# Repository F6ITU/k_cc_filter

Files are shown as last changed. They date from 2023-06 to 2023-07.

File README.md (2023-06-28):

# k_cc_filter
Simple DC filter for Power Switching Unit (12 or 45V) (codename "Boufiltre")

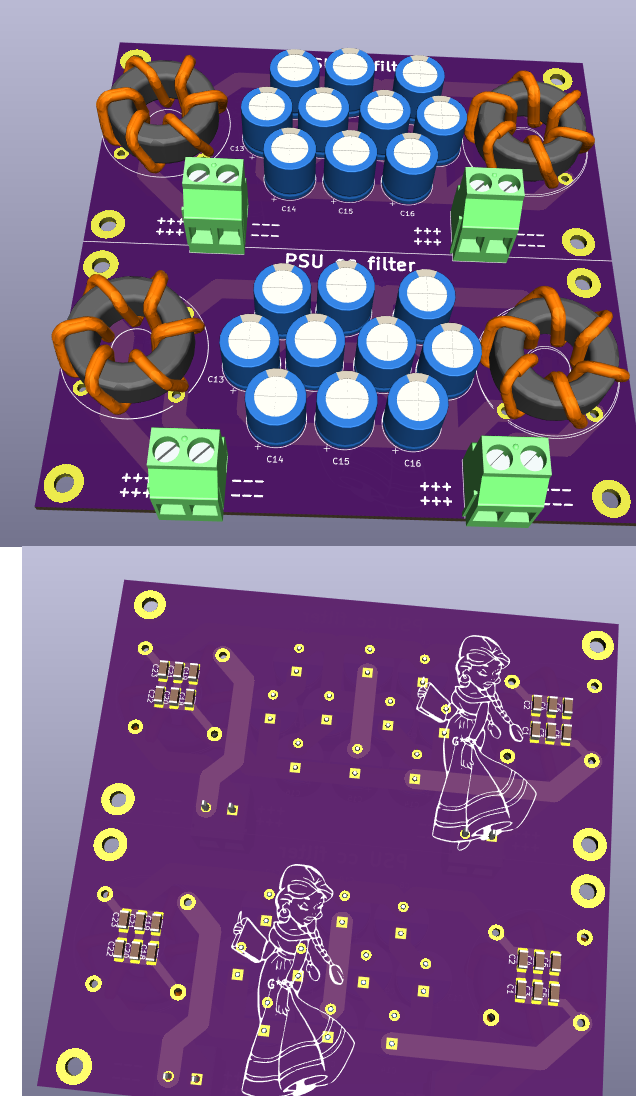
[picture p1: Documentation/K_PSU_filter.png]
Boufiltre cc filter for switching power supply


The whole network as a 100V service voltage 

L1/L4 could be omited and replaced by jumpers.

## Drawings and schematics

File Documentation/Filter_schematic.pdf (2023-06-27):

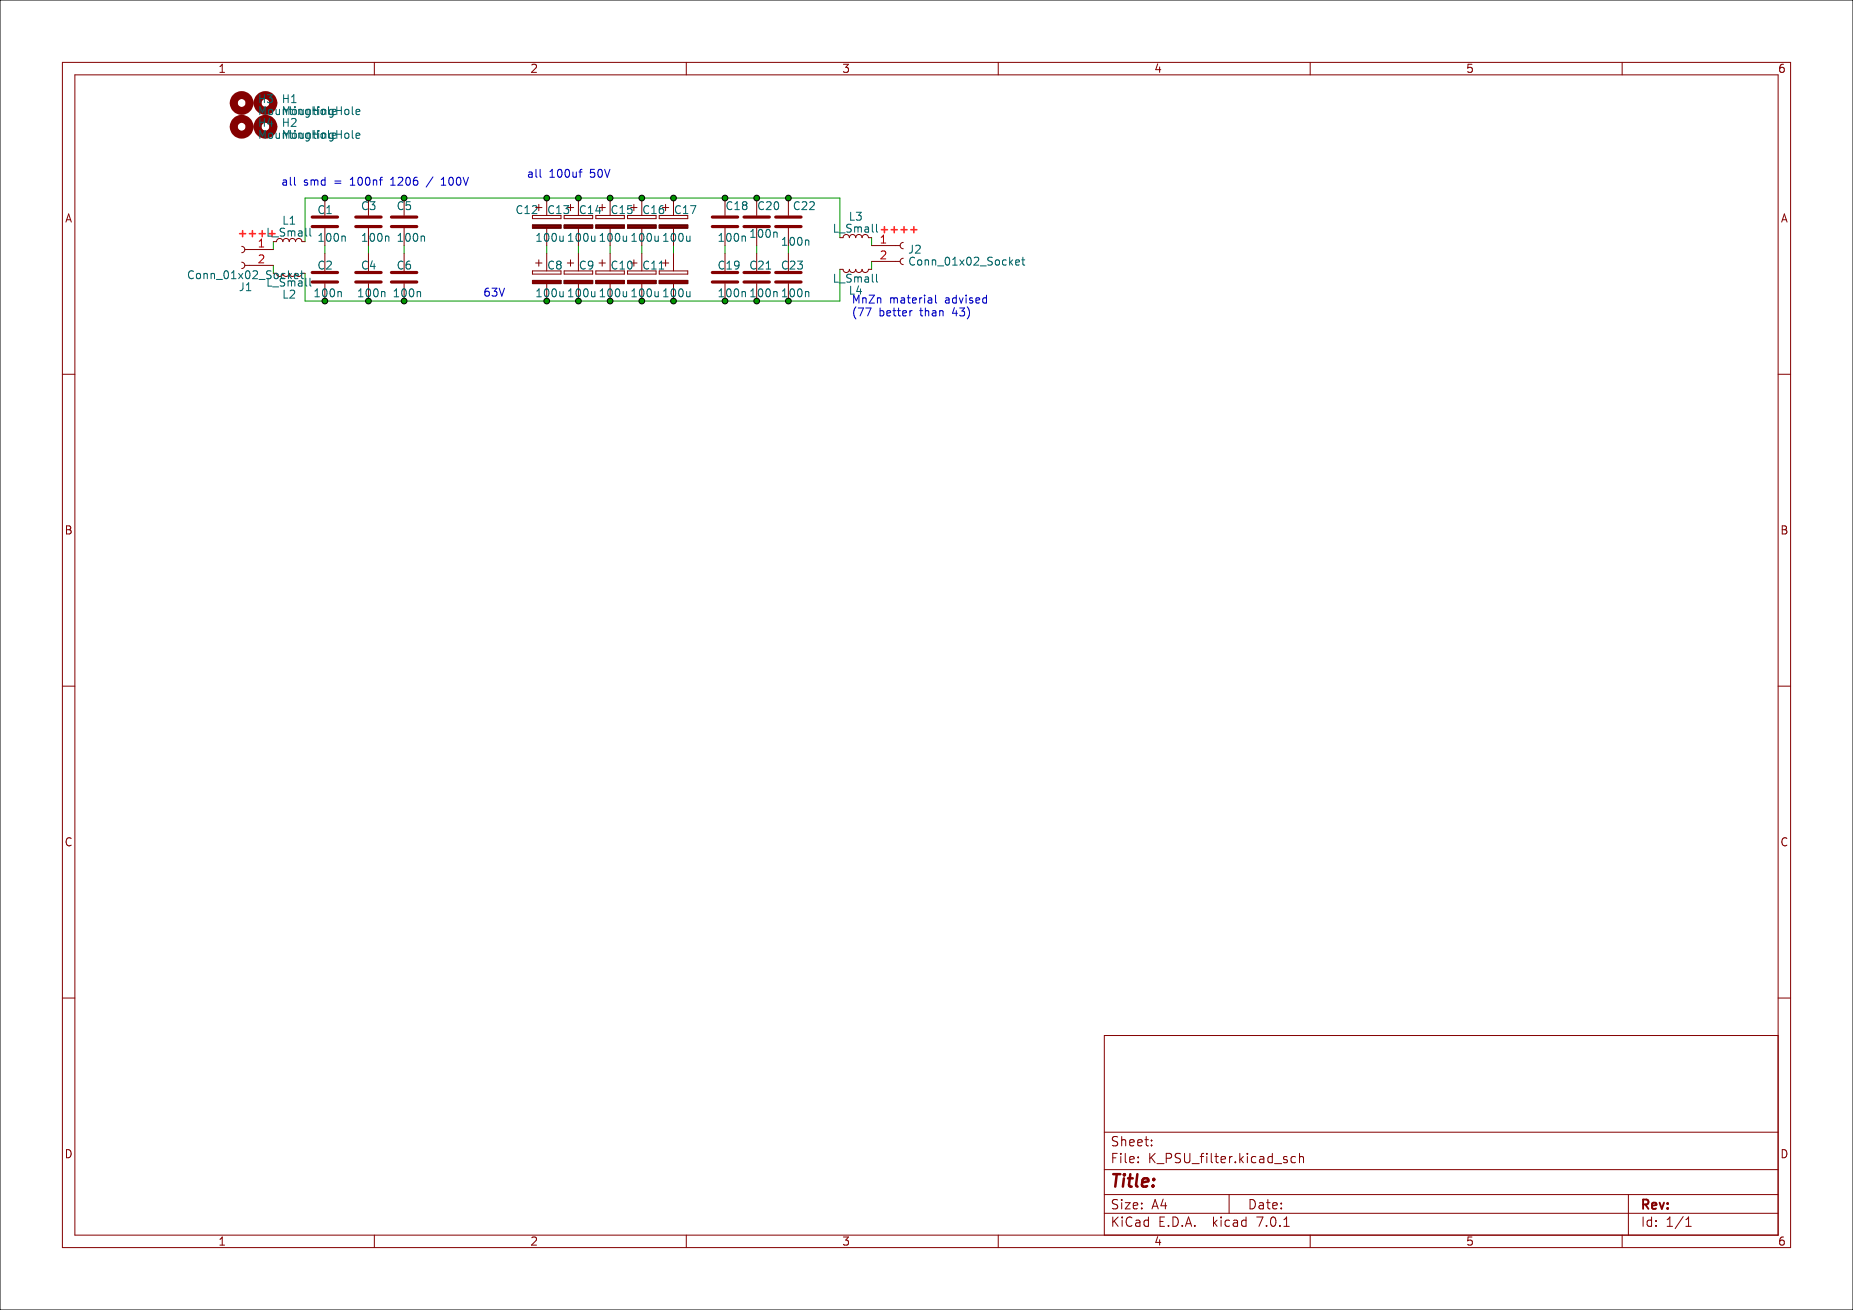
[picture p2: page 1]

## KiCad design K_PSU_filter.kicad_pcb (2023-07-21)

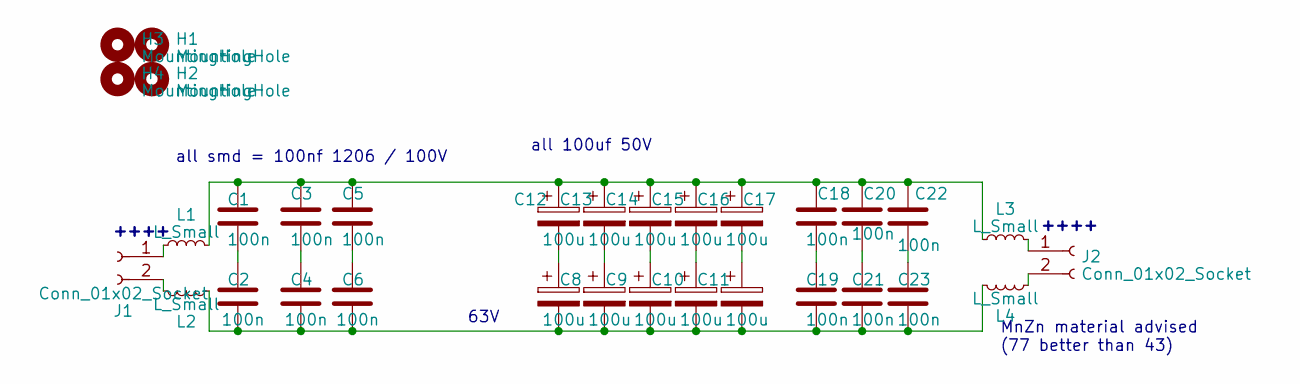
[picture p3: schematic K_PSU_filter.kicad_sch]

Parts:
C1, C2, C3, C4, C5, C6, C18, C19, C20, C21, C22, C23: 100n; C_1206_3216Metric_Pad1.33x1.80mm_HandSolder
C8, C9, C10, C11, C12, C13, C14, C15, C16, C17: 100u; CP_Radial_D10.0mm_P5.00mm
H1, H2, H3, H4: MountingHole; MountingHole_3.2mm_M3_Pad
J1, J2: Conn_01x02_Socket; 1711725
L1, L2, L3, L4: L_Small; L_Toroid_Horizontal_25x22

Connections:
unnamed: C1.1, C3.1, C5.1, C13.1, C14.1, C15.1, C16.1, C17.1, C18.1, C20.1, C22.1, L1.2, L3.1
unnamed: C1.2, C2.1
unnamed: C3.2, C4.1
unnamed: C5.2, C6.1
unnamed: C10.1, C15.2
unnamed: C2.2, C4.2, C6.2, C8.2, C9.2, C10.2, C11.2, C12.2, C19.2, C21.2, C23.2, L2.2, L4.1
unnamed: C11.1, C16.2
unnamed: C12.1, C17.2
unnamed: C8.1, C13.2
unnamed: C9.1, C14.2
unnamed: C18.2, C19.1
unnamed: C20.2, C21.1
unnamed: C22.2, C23.1
unnamed: J1.1, L1.1
unnamed: J1.2, L2.1
unnamed: J2.1, L3.2
unnamed: J2.2, L4.2

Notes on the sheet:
MnZn material advised (77 better than 43)
all smd = 100nf 1206 / 100V
63V
++++
all 100uf 50V

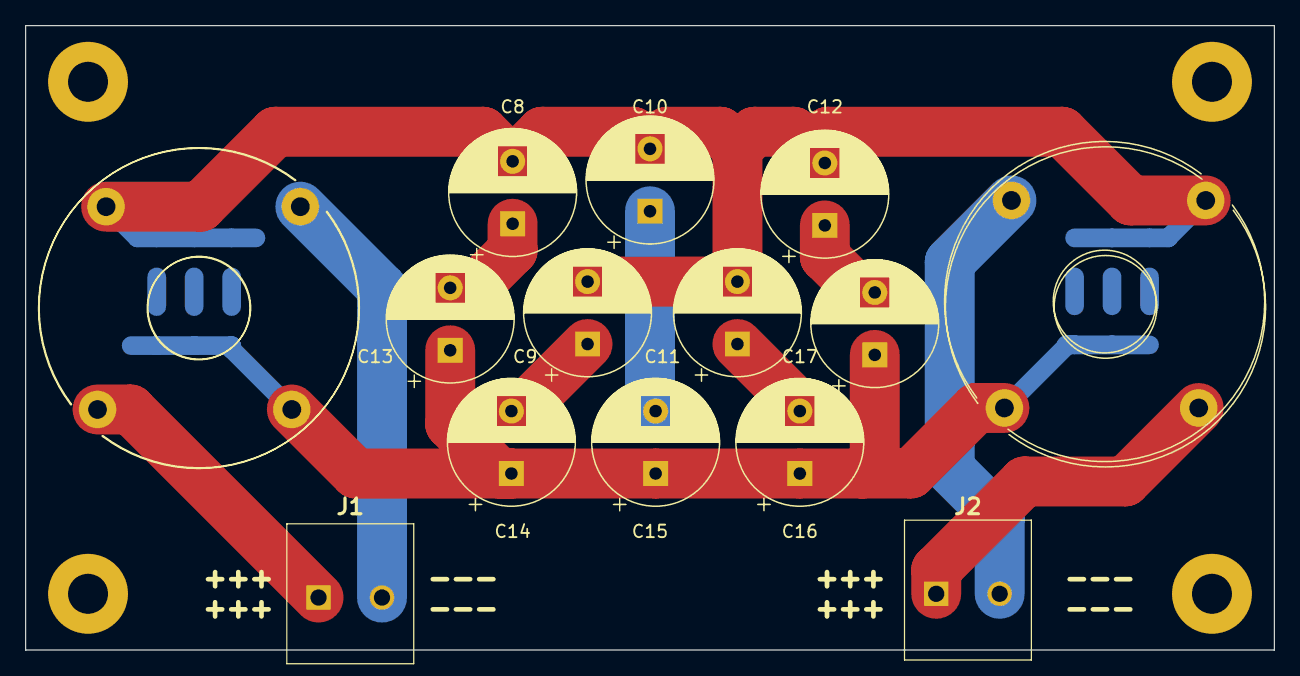
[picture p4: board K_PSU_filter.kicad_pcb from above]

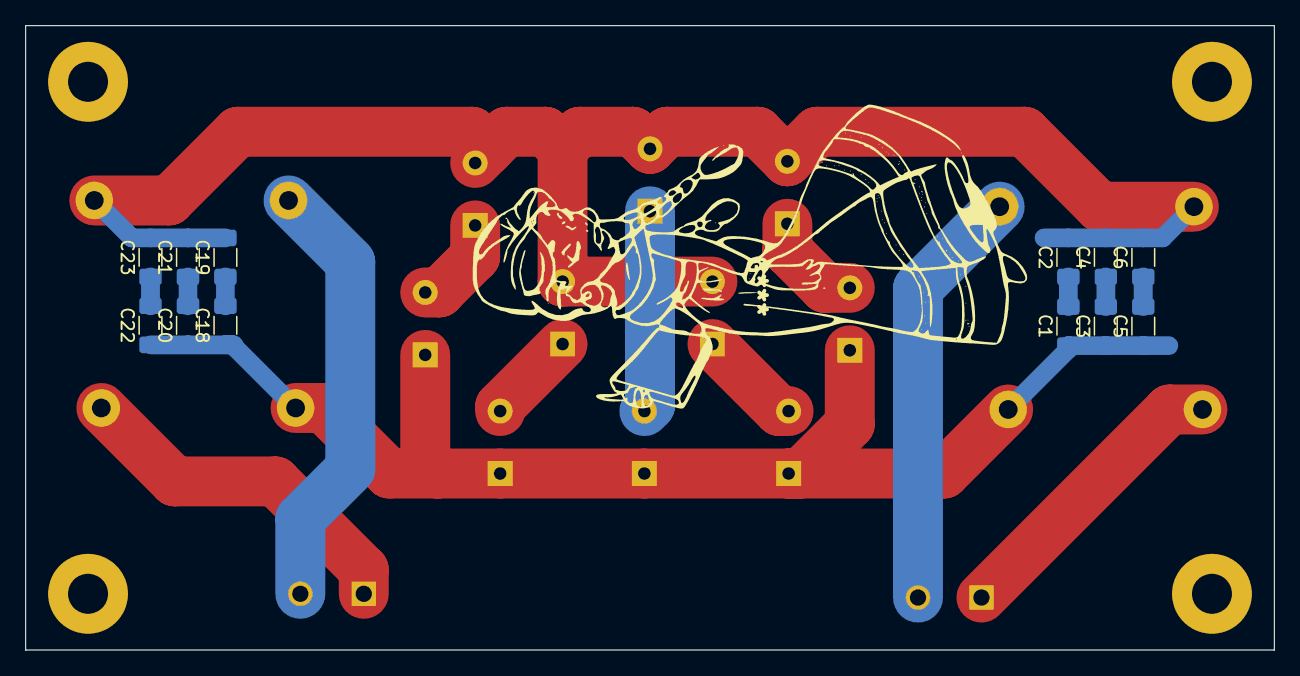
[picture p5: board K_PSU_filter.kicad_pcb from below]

Board: 2 copper layers, 100.0 x 50.0 mm, 32 parts (12 on the bottom side), 17 nets.

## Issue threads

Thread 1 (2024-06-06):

Core and wwire

2Ntthunter, 2024-06-06:
Hi which cores with how much turn is you need for filters

F6ITU, 2024-06-07:
Hi 2Ntthunter
Depending on the project (Alexandrie lpf, hpf, Zolotaref etc), all inductances are specified on the schematic. Amidon material 1, 2, 6 and 10 is used depending on the working frequency. Number of turn is determined by measuring the inductances during the assembly (with a VNA or capacimeter)
One exeption : [k_cc_filter](https://github.com/F6ITU/k_cc_filter) . This is a DC filter using material 61 or MnZn mix. Number of turns is not critical : between 20 or 30.

Using Mini Ring Core Calculator could help you to determine the winding and wire diameter, but the error margin depends on the material quality. A serious VNA measurement is the only way to reach optimum values

Just tell me what filter's project you're speaking about and I'll try to give you a more precise answer

73'
Marc

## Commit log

2023-06-27 schematic and routing completed
    [K_PSU_filter.kicad_pcb, K_PSU_filter.kicad_sch]
2023-06-27 gerber added, small silkmask mods
    [K_PSU_dual_filter-B_Cu.gbl, K_PSU_dual_filter-B_Mask.gbs, K_PSU_dual_filter-B_Paste.gbp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]
2023-06-28 new 3D capture, new gerber
2023-07-21 small routing mods, new gerber, inductors are in the same direct.
    [K_PSU_dual_filter-B_Silkscreen.gbo, K_PSU_dual_filter-F_Cu.gtl, K_PSU_dual_filter-F_Mask.gts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]
